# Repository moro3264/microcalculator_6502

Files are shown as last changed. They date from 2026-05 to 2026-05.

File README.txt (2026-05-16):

Microcalculator cu microprocesorul 6502 (WDC).

Scop
====

    Crearea unui sistem capabil sa gestioneze dispozitive auxiliare printr-un set
de functii de baza. Pe masura ce proiectul merge mai departe se vor dezvolta si alte capacitati software / hardware.

Impartirea memoriei
===================

        +-----------+
        |           |
        |           |
        |           |
        |           | 
        |    RAM    |   [0x0000, 0x7FFF] (32 KiB)
        |           |
        |           |
        |           |
        |           |
        |           |
        +-----------+
        |   ACIA    |   [0x8000, 0x800F] (16 B)
        +-----------+
        |   VIA     |   [0x8010, 0x801F] (16 B)
        +-----------+
        |   LIBER   |   [0x8020, 0x802F] (16 B)
        +-----------+
        |   LIBER   |   [0x8030, 0x803F] (16 B)
        +-----------+
        |           |
        |           |
        |           |
        |           |
        |    ROM    |   [0x8040, 0xFFFF] (32704 B)
        |           | 
        |           |
        |           |
        |           |
        +-----------+

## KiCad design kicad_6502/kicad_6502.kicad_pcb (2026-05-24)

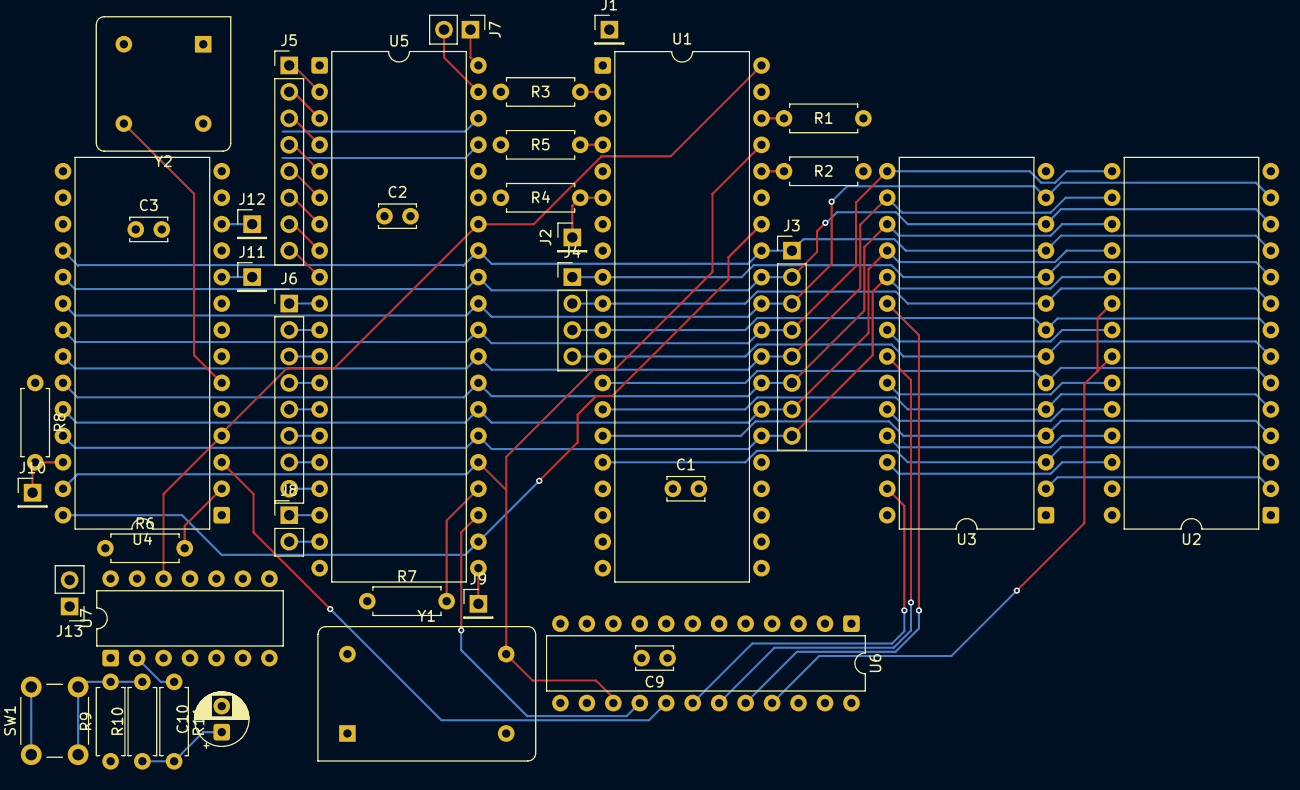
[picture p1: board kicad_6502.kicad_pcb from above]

Board: 2 copper layers, 39 parts (0 on the bottom side), 70 nets.

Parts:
C1, C2, C3, C9: 0.1uF; C_Disc_D3.4mm_W2.1mm_P2.50mm
C10: 4.7uF; CP_Radial_D5.0mm_P2.50mm
J1: /IRQ; PinHeader_1x01_P2.54mm_Vertical
J2: /NMI; PinHeader_1x01_P2.54mm_Vertical
J3: D[7...0]; PinHeader_1x08_P2.54mm_Vertical
J4: A[3...0]; PinHeader_1x04_P2.54mm_Vertical
J5: PORTB; PinHeader_1x08_P2.54mm_Vertical
J6: PORTA; PinHeader_1x08_P2.54mm_Vertical
J7: CA; PinHeader_1x02_P2.54mm_Vertical
J8: CB; PinHeader_1x02_P2.54mm_Vertical
J9: /IRQ_VIA; PinHeader_1x01_P2.54mm_Vertical
J10: /IRQ_ACIA; PinHeader_1x01_P2.54mm_Vertical
J11: TX; PinHeader_1x01_P2.54mm_Vertical
J12: RX; PinHeader_1x01_P2.54mm_Vertical
J13: PWR; PinHeader_1x02_P2.54mm_Vertical
R1, R2, R3, R4, R5, R6, R7, R8, R9, R11: 5K; R_Axial_DIN0207_L6.3mm_D2.5mm_P7.62mm_Horizontal
R10: 250K; R_Axial_DIN0207_L6.3mm_D2.5mm_P7.62mm_Horizontal
SW1: RESET; SW_PUSH_6mm
U1: CPU; DIP-40_W15.24mm
U2: EEPROM; DIP-28_W15.24mm
U3: SRAM; DIP-28_W15.24mm
U4: ACIA; DIP-28_W15.24mm
U5: VIA; DIP-40_W15.24mm
U6: ATF22V10; DIP-24_W7.62mm
U7: 74LS73; DIP-14_W7.62mm
Y1: SYS_CLK; Oscillator_DIP-14
Y2: COM_CLK; Oscillator_DIP-8

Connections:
/+5V: C1.1, C2.1, C3.1, C9.1, J13.1, R1.1, R2.1, R3.1, R4.1, R5.1, R6.1, R7.1, R8.1, R9.1, U1.8 (VDD), U2.27 (~WE), U2.28 (VCC), U3.28 (VCC), U4.15 (VCC), U5.20 (VCC), U6.24 (VCC), U7.4 (VCC), U7.5 (C), U7.6 (~R), U7.7 (J), U7.10 (K), U7.14 (J), Y1.1 (EN), Y1.14 (Vcc), Y2.1 (EN), Y2.8 (Vcc)
/A0: J4.1, U1.9 (A0), U2.10 (A0), U3.10 (A0), U4.14 (RS1), U5.38 (RS0)
/A1: J4.2, U1.10 (A1), U2.9 (A1), U3.9 (A1), U4.13 (RS0), U5.37 (RS1)
/A2: J4.3, U1.11 (A2), U2.8 (A2), U3.8 (A2), U5.36 (RS2)
/A3: J4.4, U1.12 (A3), U2.7 (A3), U3.7 (A3), U5.35 (RS3)
/A4: U1.13 (A4), U2.6 (A4), U3.6 (A4), U6.13 (IN)
/A5: U1.14 (A5), U2.5 (A5), U3.5 (A5), U6.11 (IN)
/A6: U1.15 (A6), U2.4 (A6), U3.4 (A6), U6.10 (IN)
/A7: U1.16 (A7), U2.3 (A7), U3.3 (A7), U6.9 (IN)
/A8: U1.17 (A8), U2.25 (A8), U3.25 (A8), U6.8 (IN)
/A9: U1.18 (A9), U2.24 (A9), U3.24 (A9), U6.7 (IN)
/A10: U1.19 (A10), U2.21 (A10), U3.21 (A10), U6.6 (IN)
/A11: U1.20 (A11), U2.23 (A11), U3.23 (A11), U6.5 (IN)
/A12: U1.22 (A12), U2.2 (A12), U3.2 (A12), U6.4 (IN/PD)
/A13: U1.23 (A13), U2.26 (A13), U3.26 (A13), U6.3 (IN)
/A14: U1.24 (A14), U2.1 (A14), U3.1 (A14), U6.2 (IN)
/A15: U1.25 (A15), U6.1 (CLK/IN)
/COM_CLK: U4.6 (XTAL1), Y2.5 (OUT)
/D0: J3.1, U1.33 (D0), U2.11 (D0), U3.11 (Q0), U4.18 (D0), U5.33 (D0)
/D1: J3.2, U1.32 (D1), U2.12 (D1), U3.12 (Q1), U4.19 (D1), U5.32 (D1)
/D2: J3.3, U1.31 (D2), U2.13 (D2), U3.13 (Q2), U4.20 (D2), U5.31 (D2)
/D3: J3.4, U1.30 (D3), U2.15 (D3), U3.15 (Q3), U4.21 (D3), U5.30 (D3)
/D4: J3.5, U1.29 (D4), U2.16 (D4), U3.16 (Q4), U4.22 (D4), U5.29 (D4)
/D5: J3.6, U1.28 (D5), U2.17 (D5), U3.17 (Q5), U4.23 (D5), U5.28 (D5)
/D6: J3.7, U1.27 (D6), U2.18 (D6), U3.18 (Q6), U4.24 (D6), U5.27 (D6)
/D7: J3.8, U1.26 (D7), U2.19 (D7), U3.19 (Q7), U4.25 (D7), U5.26 (D7)
/R/W: U1.34 (R/~W), U4.28 (R/~W), U5.22 (R/~W), U6.14 (I/O)
/SYS_CLK: U1.37 (ϕ0), U4.27 (ϕ2), U5.25 (ϕ2), U6.15 (I/O), U7.1 (C), Y1.8 (OUT)
//CE_ACIA: U4.3 (~CS2), U6.17 (I/O)
//CE_RAM: U3.20 (~CS), U6.20 (I/O)
//CE_ROM: U2.20 (~CS), U2.22 (~OE), U6.21 (I/O)
//CE_VIA: U5.23 (~CS2), U6.16 (I/O)
//OE_RAM: U3.22 (~OE), U6.19 (I/O)
//RESET: U1.40 (~RES), U4.4 (~RES), U5.34 (~RES), U7.12 (Q)
//WE_RAM: U3.27 (~WE), U6.18 (I/O)
GNDD: C1.2, C2.2, C3.2, C9.2, C10.2, J13.2, SW1.1, U1.21 (VSS), U2.14 (GND), U3.14 (GND), U4.1 (VSS), U5.1 (VSS), U6.12 (GND), U7.3 (K), U7.11 (GND), Y1.7 (GND), Y2.4 (GND)
unnamed: C10.1, R10.1, R11.2
unnamed: J1.1 (Pin_1_1), R5.2, U1.4 (~IRQ)
unnamed: J2.1 (Pin_1_1), R4.2, U1.6 (~NMI)
unnamed: J5.1, U5.2 (PA0)
unnamed: J5.2, U5.3 (PA1)
unnamed: J5.3, U5.4 (PA2)
unnamed: J5.4, U5.5 (PA3)
unnamed: J5.5, U5.6 (PA4)
unnamed: J5.6, U5.7 (PA5)
unnamed: J5.7, U5.8 (PA6)
unnamed: J5.8, U5.9 (PA7)
unnamed: J6.1, U5.10 (PB0)
unnamed: J6.2, U5.11 (PB1)
unnamed: J6.3, U5.12 (PB2)
unnamed: J6.4, U5.13 (PB3)
unnamed: J6.5, U5.14 (PB4)
unnamed: J6.6, U5.15 (PB5)
unnamed: J6.7, U5.16 (PB6)
unnamed: J6.8, U5.17 (PB7)
unnamed: J7.1, U5.40 (CA1)
unnamed: J7.2, U5.39 (CA2)
unnamed: J8.1, U5.18 (CB1)
unnamed: J8.2, U5.19 (CB2)
unnamed: J9.1 (Pin_1_1), U5.21 (~IRQ)
unnamed: J10.1 (Pin_1_1), R8.2, U4.26 (~IRQ)
unnamed: J11.1 (Pin_1_1), U4.10 (TxD)
unnamed: J12.1 (Pin_1_1), U4.12 (RxD)
unnamed: R9.2, R10.2, SW1.2
unnamed: R2.2, U1.36 (BE)
unnamed: R3.2, U1.2 (RDY)
unnamed: R1.2, U1.38 (~SO)
unnamed: R6.2, U4.2 (CS1)
unnamed: R7.2, U5.24 (CS1)
unnamed: R11.1, U7.2 (~R)

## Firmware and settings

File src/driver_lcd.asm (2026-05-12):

;   Driver pentru afisaje LCD alfanumerice (HD44780)
;   Subrutine:
;   *   LCD_INIT
;   *   LCD_CMD
;   *   LCD_CHR
;   *   LCD_STR
;   *   LCD_CLEAR
;
;   Pe viitor:
;   *   se va renunta la metoda cu decalaj soft
;   *   se vor generaliza instructiunile pentru LCD-uri de diferite dimensiuni: 8x2, 16x2, 24

.include "adrese.asm"

.CODE

LCD_INIT:
    PHA

    LDA #$02
    JSR LCD_CMD
    LDA #$28
    JSR LCD_CMD
    LDA #$06
    JSR LCD_CMD
    LDA #$0C
    JSR LCD_CMD
    JSR LCD_CLEAR

    PLA
    RTS

;   PORTB ~ LCD
;   7   6   5   4   3   2   1   0
;   7   6   5   4   X   RS  E   X
LCD_CMD:
    PHA 

    STA _LCD_VAL_TMP
    AND #$F0
    ORA #$02           ;   E = 1
    STA PORTB

    LDA #$80
    JSR DELAY

    AND #$F0
    STA PORTB           ;E = 0

    LDA #$80
    JSR DELAY

    LDA _LCD_VAL_TMP
    ROL A           
    ROL A           
    ROL A           
    ROL A           
    AND #$F0
    ORA #$02        
    STA PORTB       

    LDA #$80
    JSR DELAY

    AND #$F0
    STA PORTB

    LDA #$80
    JSR DELAY
    
    PLA
    RTS

;   PORTB
;   7   6   5   4   3   2   1   0
;   7   6   5   4   X   RS  E   X

LCD_CHR:
    PHA

    STA _LCD_VAL_TMP    ;
    AND #$F0            ;
    ORA #$06            ;   RS = 1 si E = 1

    STA PORTB
    LDA #$80
    JSR DELAY

    AND #$F4            ;   RS = 1 si E = 0

    STA PORTB
    LDA #$80
    JSR DELAY

    LDA _LCD_VAL_TMP
    ROL A
    ROL A
    ROL A
    ROL A
    AND #$F0
    ORA #$06        ;   RS = 1 si E = 1

    STA PORTB
    LDA #$80
    JSR DELAY

    AND #$F4        ;   RS = 1 si E = 0

    STA PORTB
    LDA #$80
    JSR DELAY

    PLA
    RTS

LCD_STR: 
    PHA
    PHY
    LDY #$00
@LCD_STR_AFISARE_CHR:
    LDA (_STR_ADDR), Y
    BEQ @LCD_STR_FINAL
    JSR LCD_CHR
    INY
    JMP @LCD_STR_AFISARE_CHR
@LCD_STR_FINAL:
    PLY
    PLA

    RTS
    
DELAY:
    PHA
    PHX
    LDA #$FF
@DELAY_1:
    TAX
@DELAY_0:
    DEX
    BNE @DELAY_0
    DEC
    BNE @DELAY_1
    PLX
    PLA
    RTS

LCD_CLEAR:
    PHA
    LDA #$01
    JSR LCD_CMD
    LDA #$80
    JSR LCD_CMD
    PLA
    RTS

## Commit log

2026-05-09 schimbari la numele unor variabile
2026-05-10 kicad dir adaugat
2026-05-11 fisiere kicad
    [microcalculator_6502.kicad_pcb, microcalculator_6502.kicad_sch]
2026-05-11 LCD-ul nu va mai face parte din sistem dar va putea fi controlat in caz ca este conectat la placa
2026-05-12 schimbari pentru harta de memorie
    [harta_de_memorie.cfg]
2026-05-13 mici schimbari
    [harta_de_memorie.cfg]
2026-05-13 Altele. Sper ca de acuma sa fie gata setupu la workflow
2026-05-15 diagrama actualizata
    [microcalculator_6502.kicad_pcb, microcalculator_6502.kicad_sch]
2026-05-16 mici schimbari si adaugiri
    [harta_de_memorie.cfg]
2026-05-17 test de functionare
2026-05-22 inceput de logica pentru incarcarea programelor prin UART
2026-05-24 schimbari kicad
    [kicad_6502.kicad_pcb, kicad_6502.kicad_sch, microcalculator_6502.kicad_pcb]
